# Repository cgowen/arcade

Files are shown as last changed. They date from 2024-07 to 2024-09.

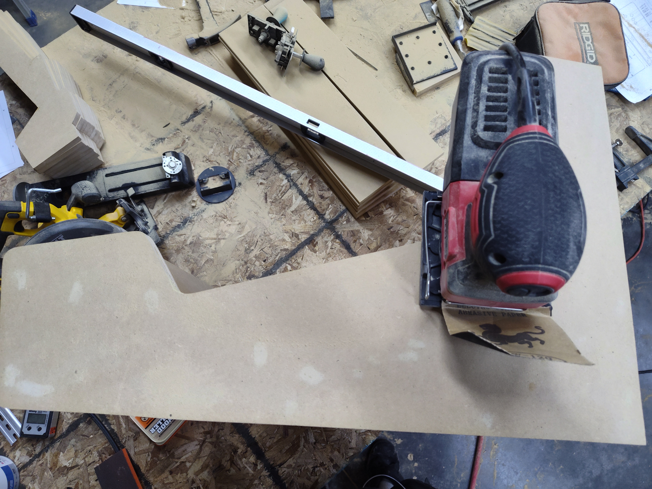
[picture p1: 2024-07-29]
Build Photos/IMG_20240721_163146368_HDR.jpg

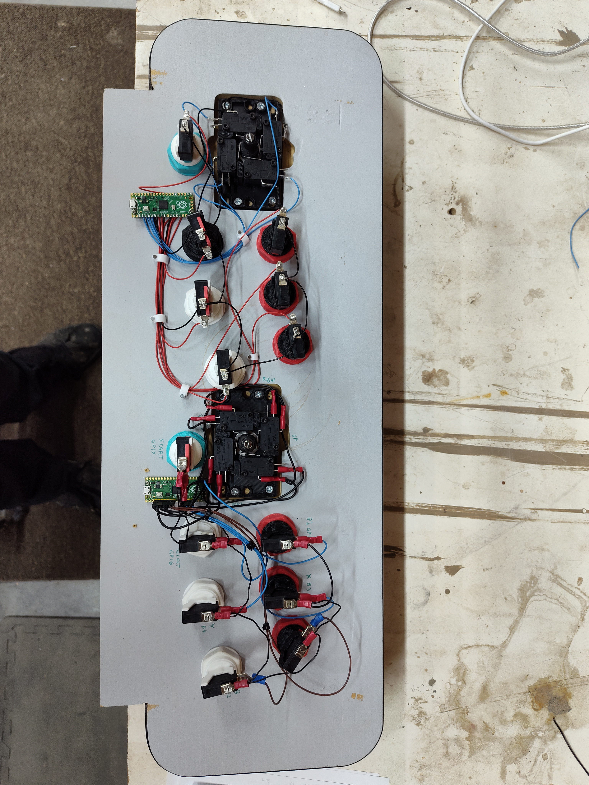
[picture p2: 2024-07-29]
Build Photos/IMG_20240728_184047468.jpg

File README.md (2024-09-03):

This project aims to be a skill building excercise for CAD design, woodworking and electronics with some 3D printing mixed in.
This page is meant to be a project log as well as a bill of materials for the project



Project links:
OnShape cabinet assembly: https://cad.onshape.com/documents/2fd70302999bd67d294d9c58/w/49d1ede729af55697e110dd8/e/55eb390648f6f1f8dbbdfb2d

3D printed button assembly: https://cad.onshape.com/documents/6f03fd3a26405f290bf9d3a9/w/7fcbac6da55869d88fd815f0/e/7aa5c642de203e99c9db4843

Joystick Assembly: https://cad.onshape.com/documents/1d7793801d2a4d8de748bbaa/w/73db9a26cb0c9d3e88edd5c2/e/f8327efe855c3a30d43a8055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

Raspberry pi pico gamepad: (https://gp2040-ce.info/)

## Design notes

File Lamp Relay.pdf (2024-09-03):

To Audio Amplifier (5V & GND)

To relay (GPIO14, 5V, GND)

To Rpi 4 power switch
(GPIO3 & GND)

VCC
IN
GND

NC
COM
NO

## Relay

# HIGH VOLTAGE POWER UNPLUG BEFORE WIRING!!

(Wire Nut if needed)

On the SD card in the raspberry pi there is a partition named boot.

### there you will find a file named: recalbox-user-config.txt

we need to add the "enable_uart=1" to the bottom of the file.

### the red "dtoverlay" command is only for the raspberry pi 4's power switches (if you are using a raspberry pi 5 then disregard this line)

A relay is an electro magnetic switch that can handle a larger load than the raspberry pi can power by itself.

In this case that is a high voltage AC load (alternating current) Connecting this to the Pi would certainly fry it.. In fact, connecting this to us could fry us also!

Be careful and unplug your machine before wiring and have an adult present to double check your connections before testing.

This setup is using the GPIO serial port pin on the raspberry pi as a signal to turn on the relay causing the light to turn on.
Once the Raspberry Pi turns off the serial port is also shutdown causing the light to turn off.

# Change to your needs

#uncomment if you get no picture on HDMI for a default "safe" mode #hdmi_safe=1

#uncomment to force a specific HDMI mode (this will force VGA) #hdmi_group=1

#hdmi_mode=1

#Sound output. Set to 0 or comment for autodetect, 1 for DVI, 2 to force HDMI. #hdmi_drive=2

config_hdmi_boost=0

#uncomment for composite PAL

#sdtv_mode=2

#uncomment for lirc-rpi

#dtoverlay=lirc-rpi

#uncomment if you have chinese TV display and display is garbled or slow #hdmi_ignore_edid=0xa5000080

overscan_scale=0
gpio=14=op,dh
dtoverlay=gpio-shutdown,gpio_pin=3,active_low=1,debounce=1500
enable_uart=1

/boot/recalbox-user-config.txt

# Software Configuration:

# Wiring:

Cut open insulation around romex wire to get to black wire inside. connect one side of the black wire you cut to the COM terminal and the other side to the NO terminal. NO is short for "normally open" which means that by default the connection is not closed until a signal is present to tell the relay to turn on.

Only the black wire needs to be cut but if you cut the others use wire nuts to put them back together
(tighten the nuts well and make sure there are no extra wires hanging out!)

GPIO Header location

# What is a relay?

The GND and 5V connections may be different on your board from what is shown here. The exact pin location doesnt matter so long as the connections are correct.
All GND pins are connected together and both 5V lines are also connected.

The important thing to pay attention to is that 5V and GND are not mixed up and that the GPIO pins are connected to the header where they need to be.

GPIO14 = relay in
GPIO3 = power switch (rpi 4 only)

# Notice!

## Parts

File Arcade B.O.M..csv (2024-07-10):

 |  |  |  |  |  | OnShape CAD Model
QTY | UNIT | DESCRIPTION | VENDOR | PRICE | TIOTAL | PURPOSE
1 | EA | Short Micro USB Cable 1ft [5 Pack] USB 2.0 Micro USB Charging Cable Android Charger Cord for Samsung Galaxy S7 Edge S6 J7 Note 5 LG Kindle Sony PS4 TV Stick Smartphones (Black) | Amazon | $1.59 | $1.59 | Connecting Raspberry Pis to Picos
1 | EA | 19" Dell P1913T 1400x1050 LCD Monitors | ebay | $23.00 | $23.00 | Arcade screen
8 | EA | 125V/250V 16A SPDT Snap Action Button Micro Limit Switch for Microwave Oven Door Arcade KW3 by MUZHI(12Pack) | Amazon | $0.63 | $5.06 | Each arcade controller button assembly
1 | 10 FT | 100FT 20AWG Electrical Wire, 20/2 Gauge Oxygen Free Copper 12V/24V DC Red Black Zip Cord Wire Car Audio Extension Wire, LED Strip Lights Hookup Wire for Led Strips Single Color 3528 5050 | Amazon | $1.60 | $1.60 | Switch and Joystick wiring.
1 | EA | Sanwa JLF OEM Shaft | Paradise Arcade Shop | $2.00 | $2.00 | Arcade Joystick Assemblies
1 | EA | PAS JLF 2 lbf Custom Spring | Paradise Arcade Shop | $1.25 | $1.25 | Arcade Joystick Assemblies
3 | EA | Koala Printable Clear Sticker Paper - ONLY for LASER Printer - 8.5x11 Inch 20 Sheets Full Sheet 100% Transparent Label Paper for DIY Personalized Decals, Labels | Amazon | $0.45 | $1.35 | Decals
1 | EA | Raspberry Pi Pico RP2040 microcontroller - in US Stock, Ready to Ship (4 Pack) | Amazon | $5.63 | $5.63 | input controller
1 | EA | Raspberry Pi 5 - 4 GB RAM | Adafruit | $60.00 | $60.00 | Host Computer
0.25 | EA | MDF 4ft x 8ft x 3/4in Sheet |  | $60.00 | $15.00
1 | EA | Plexiglass 2ft x 3ft x 1/8in sheet |  | $39.00 | $39.00
 |  |  |  | Grand Total: | $155.47 | (per cabinet)

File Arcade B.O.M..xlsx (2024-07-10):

QTY | UNIT | DESCRIPTION | VENDOR | PRICE | TIOTAL | PURPOSE
1 | EA | Short Micro USB Cable 1ft [5 Pack] USB 2.0 Micro USB Charging Cable Android Charger Cord for Samsung Galaxy S7 Edge S6 J7 Note 5 LG Kindle Sony PS4 TV Stick Smartphones (Black) | Amazon (https://www.amazon.com/Android-Compatible-Smartphones-Charging-Stations/dp/B095JZSHXQ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) | $1.59 | $1.59 | Connecting Raspberry Pis to Picos
1 | EA | 19" Dell P1913T 1400x1050 LCD Monitors | ebay | $23.00 | $23.00 | Arcade screen
8 | EA | 125V/250V 16A SPDT Snap Action Button Micro Limit Switch for Microwave Oven Door Arcade KW3 by MUZHI(12Pack) | Amazon (https://www.amazon.com/dp/B083C113YL?ref=ppx_yo2ov_dt_b_product_details&th=1) | $0.63 | $5.06 | Each arcade controller button assembly
1 | 10 FT | 100FT 20AWG Electrical Wire, 20/2 Gauge Oxygen Free Copper 12V/24V DC Red Black Zip Cord Wire Car Audio Extension Wire, LED Strip Lights Hookup Wire for Led Strips Single Color 3528 5050 | Amazon (https://www.amazon.com/dp/B088RCCHTG?psc=1&ref=ppx_yo2ov_dt_b_product_details) | $1.60 | $1.60 | Switch and Joystick wiring.
1 | EA | Sanwa JLF OEM Shaft | Paradise Arcade Shop (https://paradisearcadeshop.com/collections/joystick-actuators-shafts/products/sanwa-jlf-oem-shaft) | $2.00 | $2.00 | Arcade Joystick Assemblies
1 | EA | PAS JLF 2 lbf Custom Spring | Paradise Arcade Shop (https://paradisearcadeshop.com/products/pas-jlf-2-lbf-custom-spring) | $1.25 | $1.25 | Arcade Joystick Assemblies
3 | EA | Koala Printable Clear Sticker Paper - ONLY for LASER Printer - 8.5x11 Inch 20 Sheets Full Sheet 100% Transparent Label Paper for DIY Personalized Decals, Labels | Amazon (https://www.amazon.com/gp/product/B087CNQ75R/ref=ppx_yo_dt_b_asin_title_o01_s00?ie=UTF8&psc=1) | $0.45 | $1.35 | Decals
1 | EA | Raspberry Pi Pico RP2040 microcontroller - in US Stock, Ready to Ship (4 Pack) | Amazon (https://www.amazon.com/Raspberry-Pi-Pico-RP2040-microcontroller/dp/B09437S9X4) | $5.63 | $5.63 | input controller
1 | EA | Raspberry Pi 5 - 4 GB RAM | Adafruit (https://www.adafruit.com/product/5812?gad_source=1) | $60.00 | $60.00 | Host Computer
 |  | MDF
 |  | Plexiglass
 |  | Lights for marquee?
 |  |  |  | Grand Total: | $101.47

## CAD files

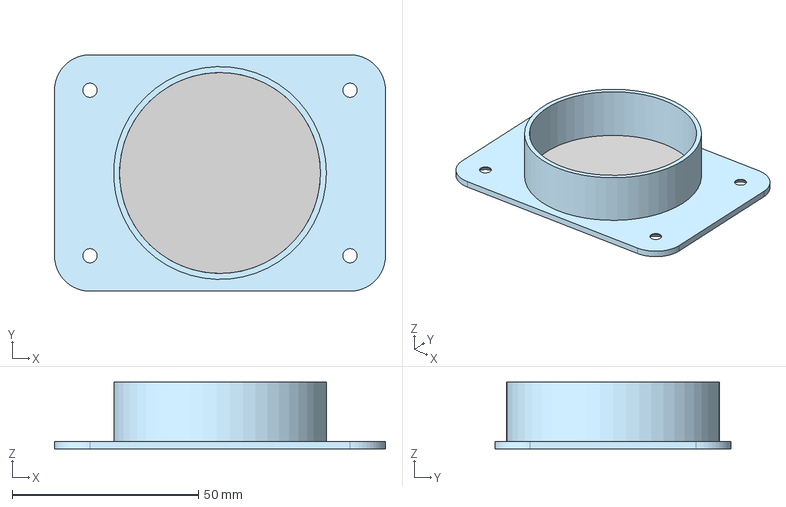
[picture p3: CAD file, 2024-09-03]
3D Printed Parts/Speaker Grill.step
88.9 x 63.5 x 17.9 mm

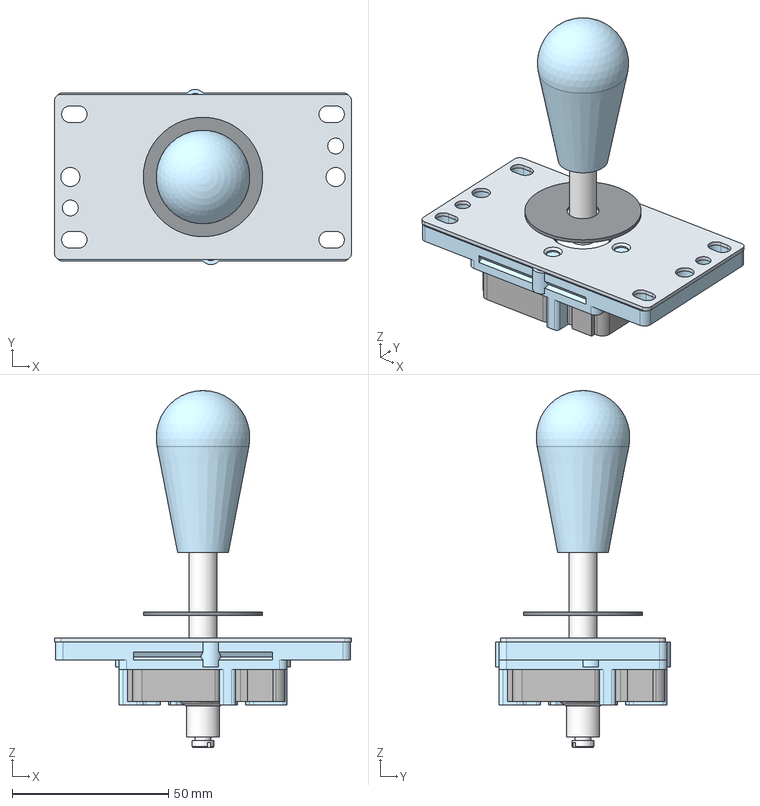
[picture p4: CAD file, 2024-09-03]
3D Printed Parts/Joystick Assm.step
95.0 x 56.0 x 114.2 mm
plate
switch body x 4
Joystick Body
pivot
Plastic Cover
knob
spring catch (top)
spring catch (btm)

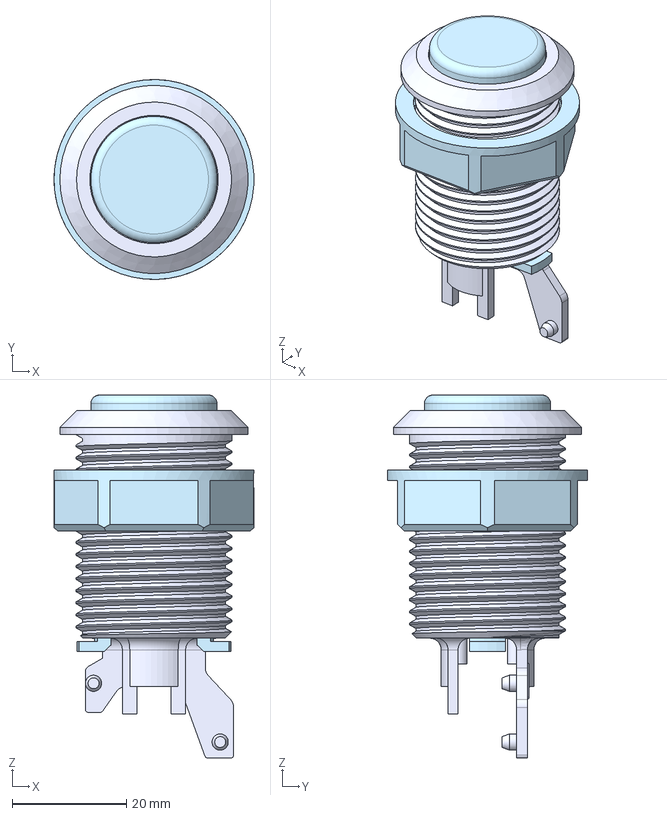
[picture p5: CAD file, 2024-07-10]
3D Printed Parts/Button Export.step
35.1 x 35.1 x 63.6 mm
Nut
Spring
Button

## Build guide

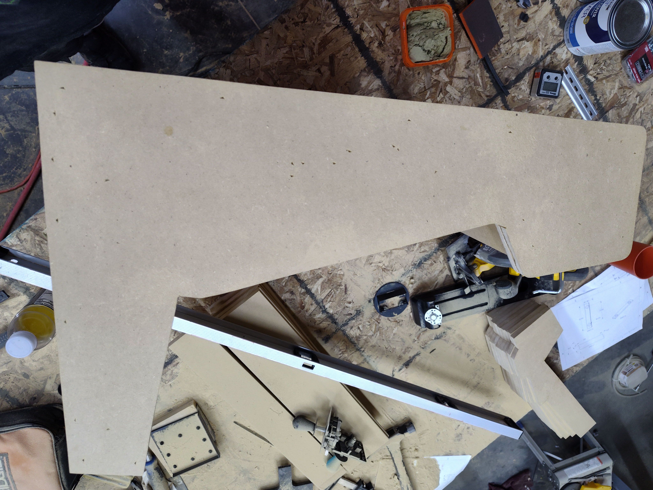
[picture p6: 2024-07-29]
Build Photos/IMG_20240721_162840555_HDR.jpg

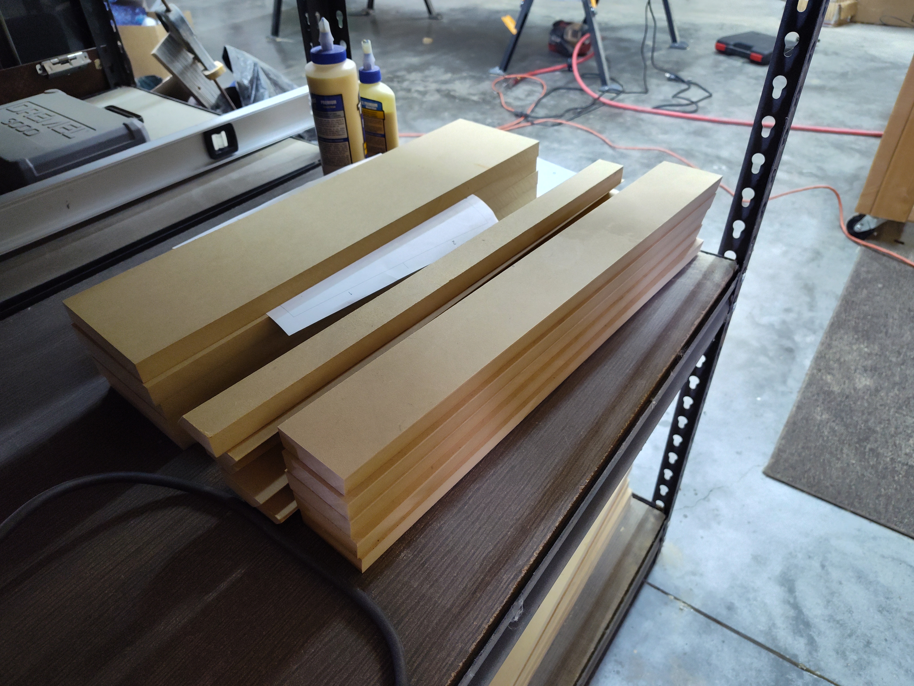
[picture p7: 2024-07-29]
Build Photos/IMG_20240721_172738716_HDR.jpg

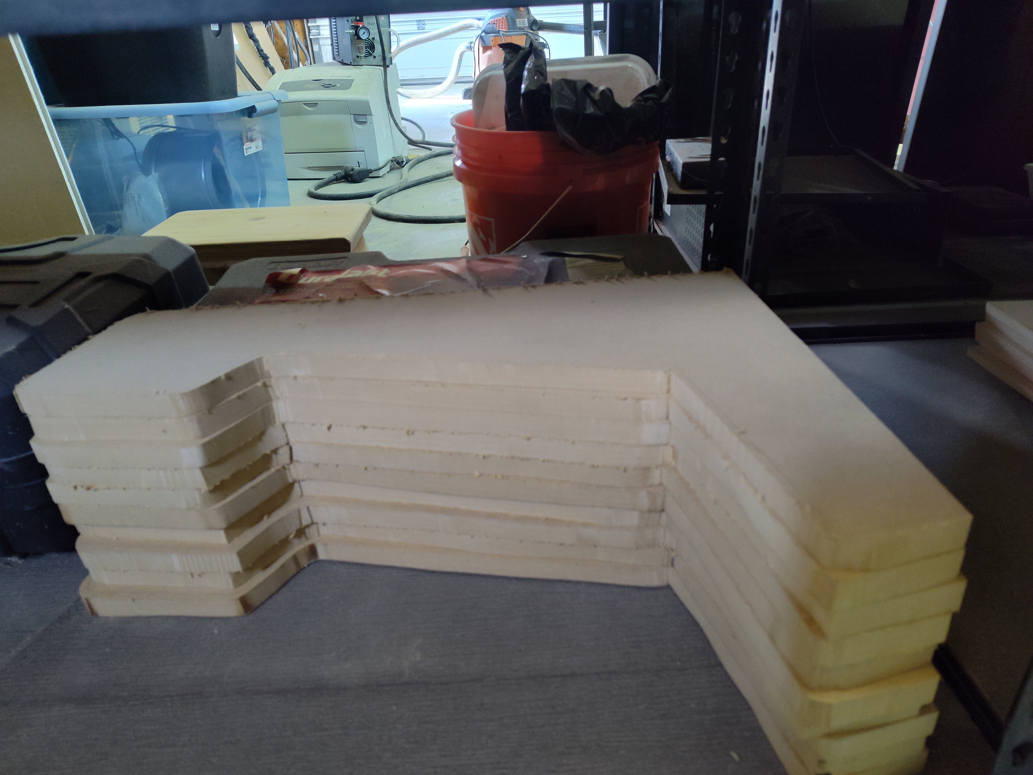
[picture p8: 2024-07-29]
Build Photos/IMG_20240721_172726751_HDR.jpg

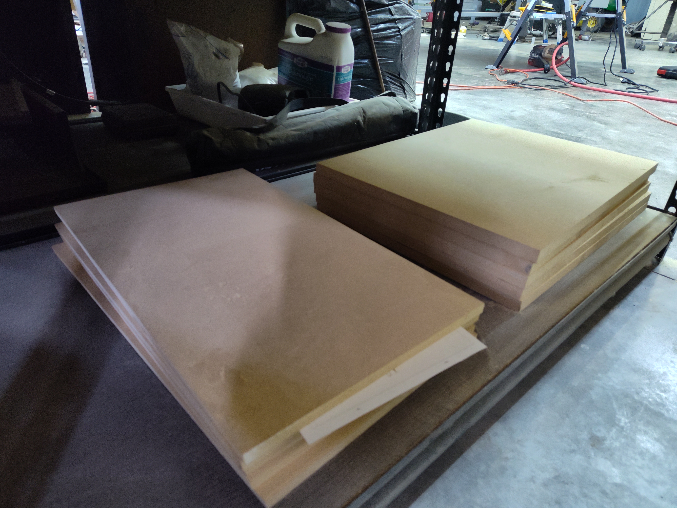
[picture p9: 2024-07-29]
Build Photos/IMG_20240721_172732919_HDR.jpg

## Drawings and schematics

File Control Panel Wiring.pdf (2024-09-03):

# Control Panel (Bottom)

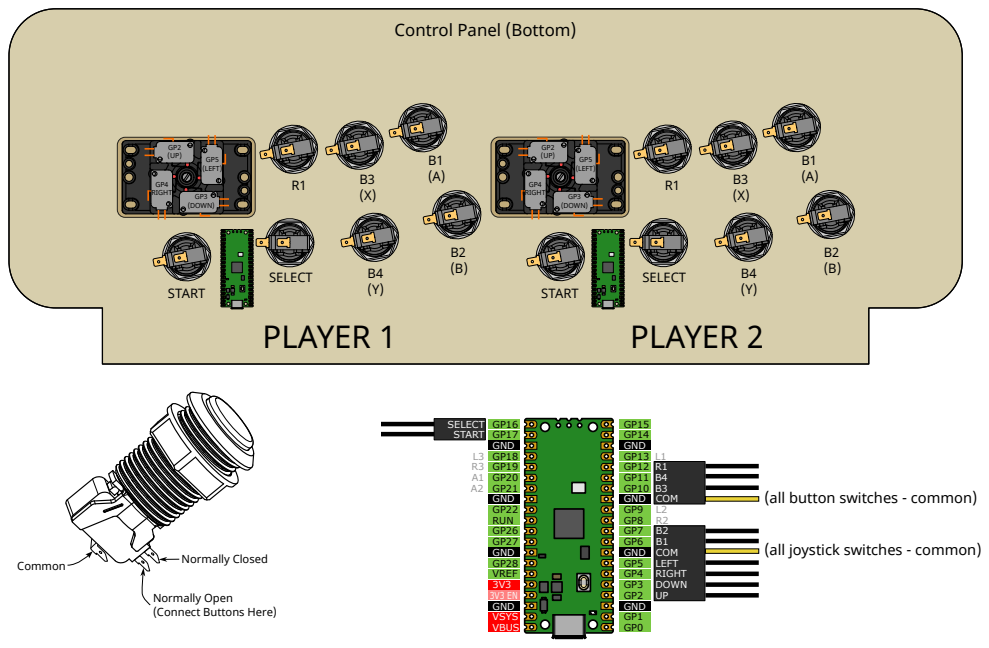
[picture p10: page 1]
GND; VBUS; VSYS; VREF; RUN; DOWN; RIGHT; LEFT; START; SELECT; COM; (all button switches - common); (LEFT); (RIGHT); (DOWN); PLAYER 1; PLAYER 2; Common; Normally Closed

(all joystick switches - common)

Normally Open
(Connect Buttons Here)

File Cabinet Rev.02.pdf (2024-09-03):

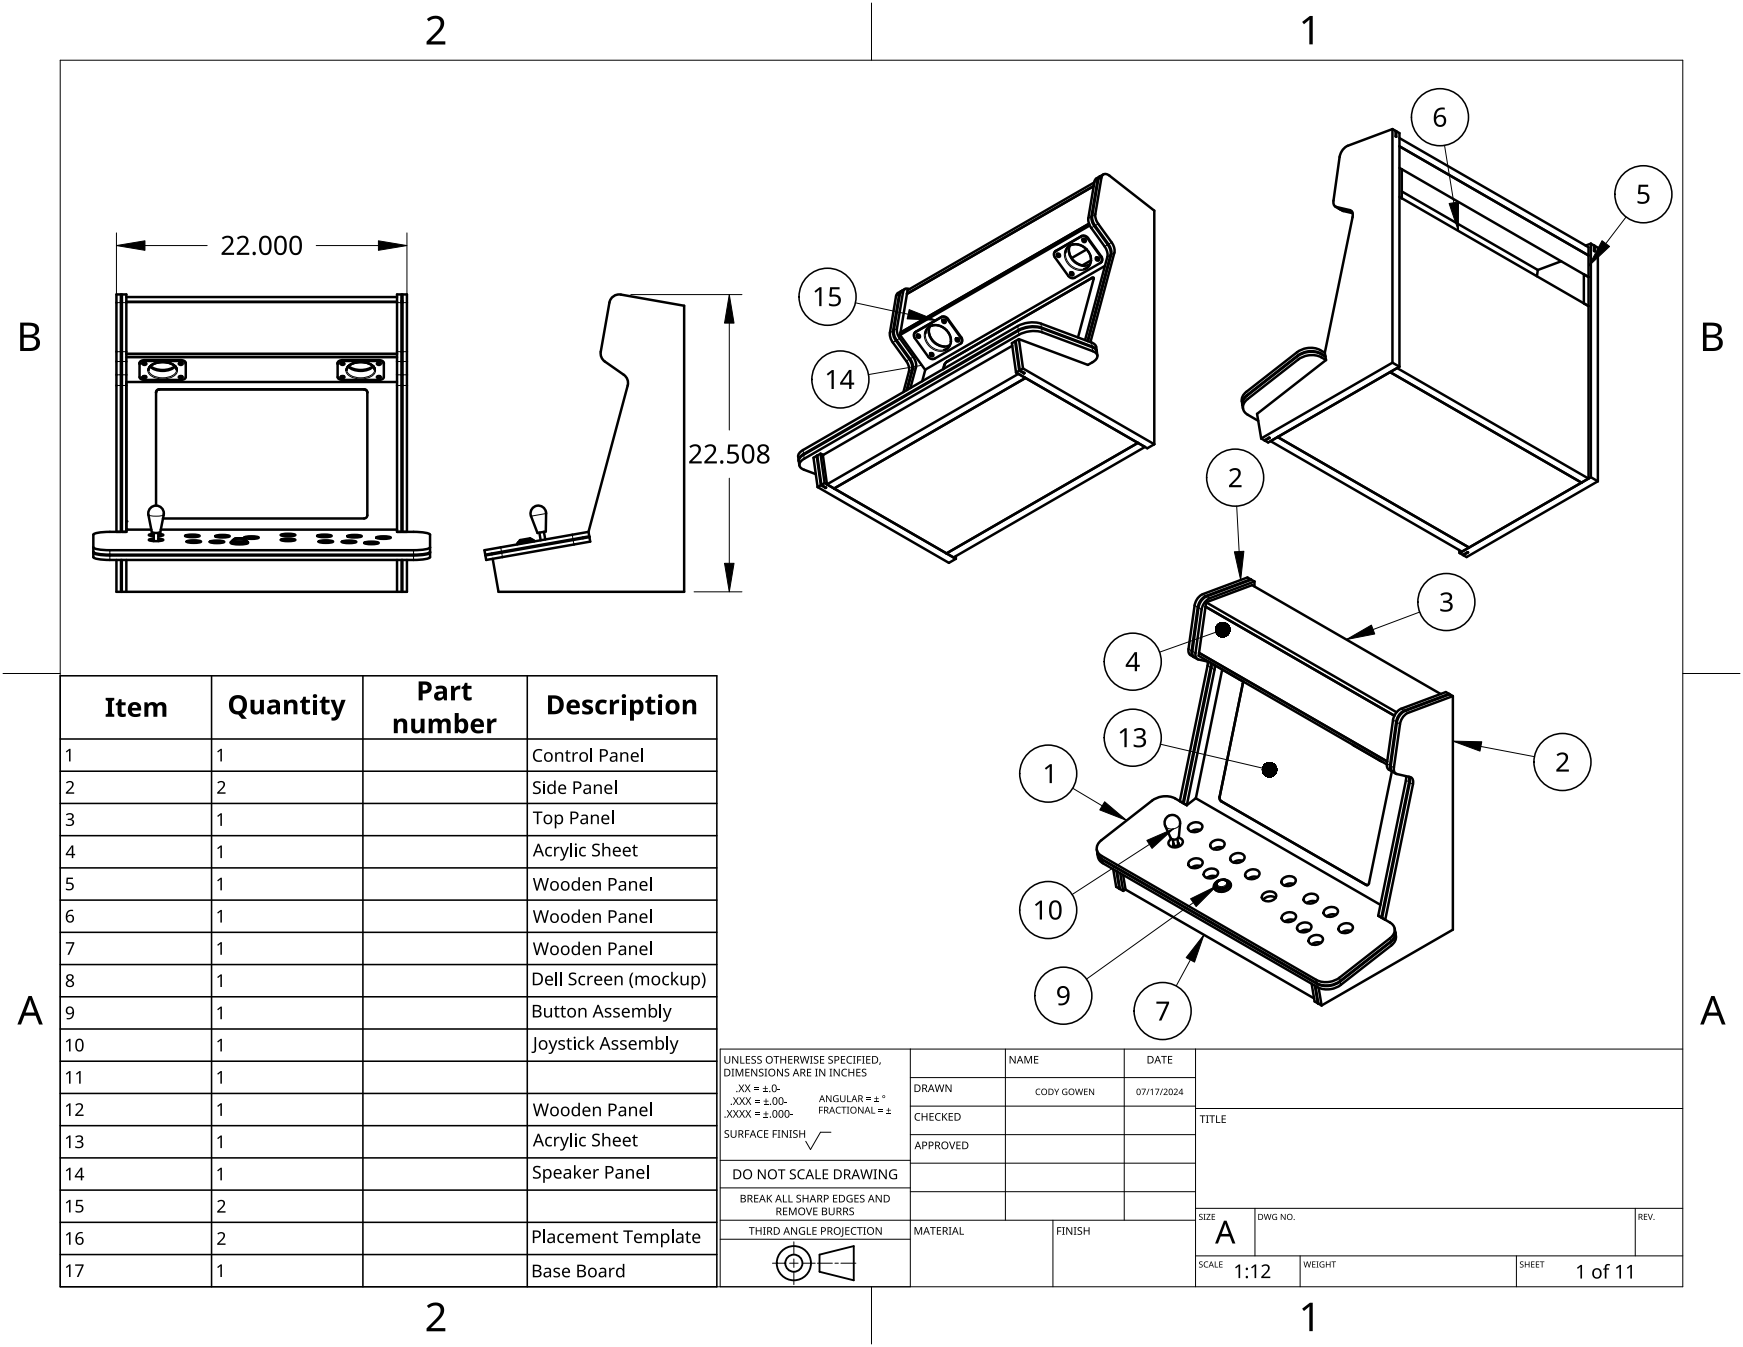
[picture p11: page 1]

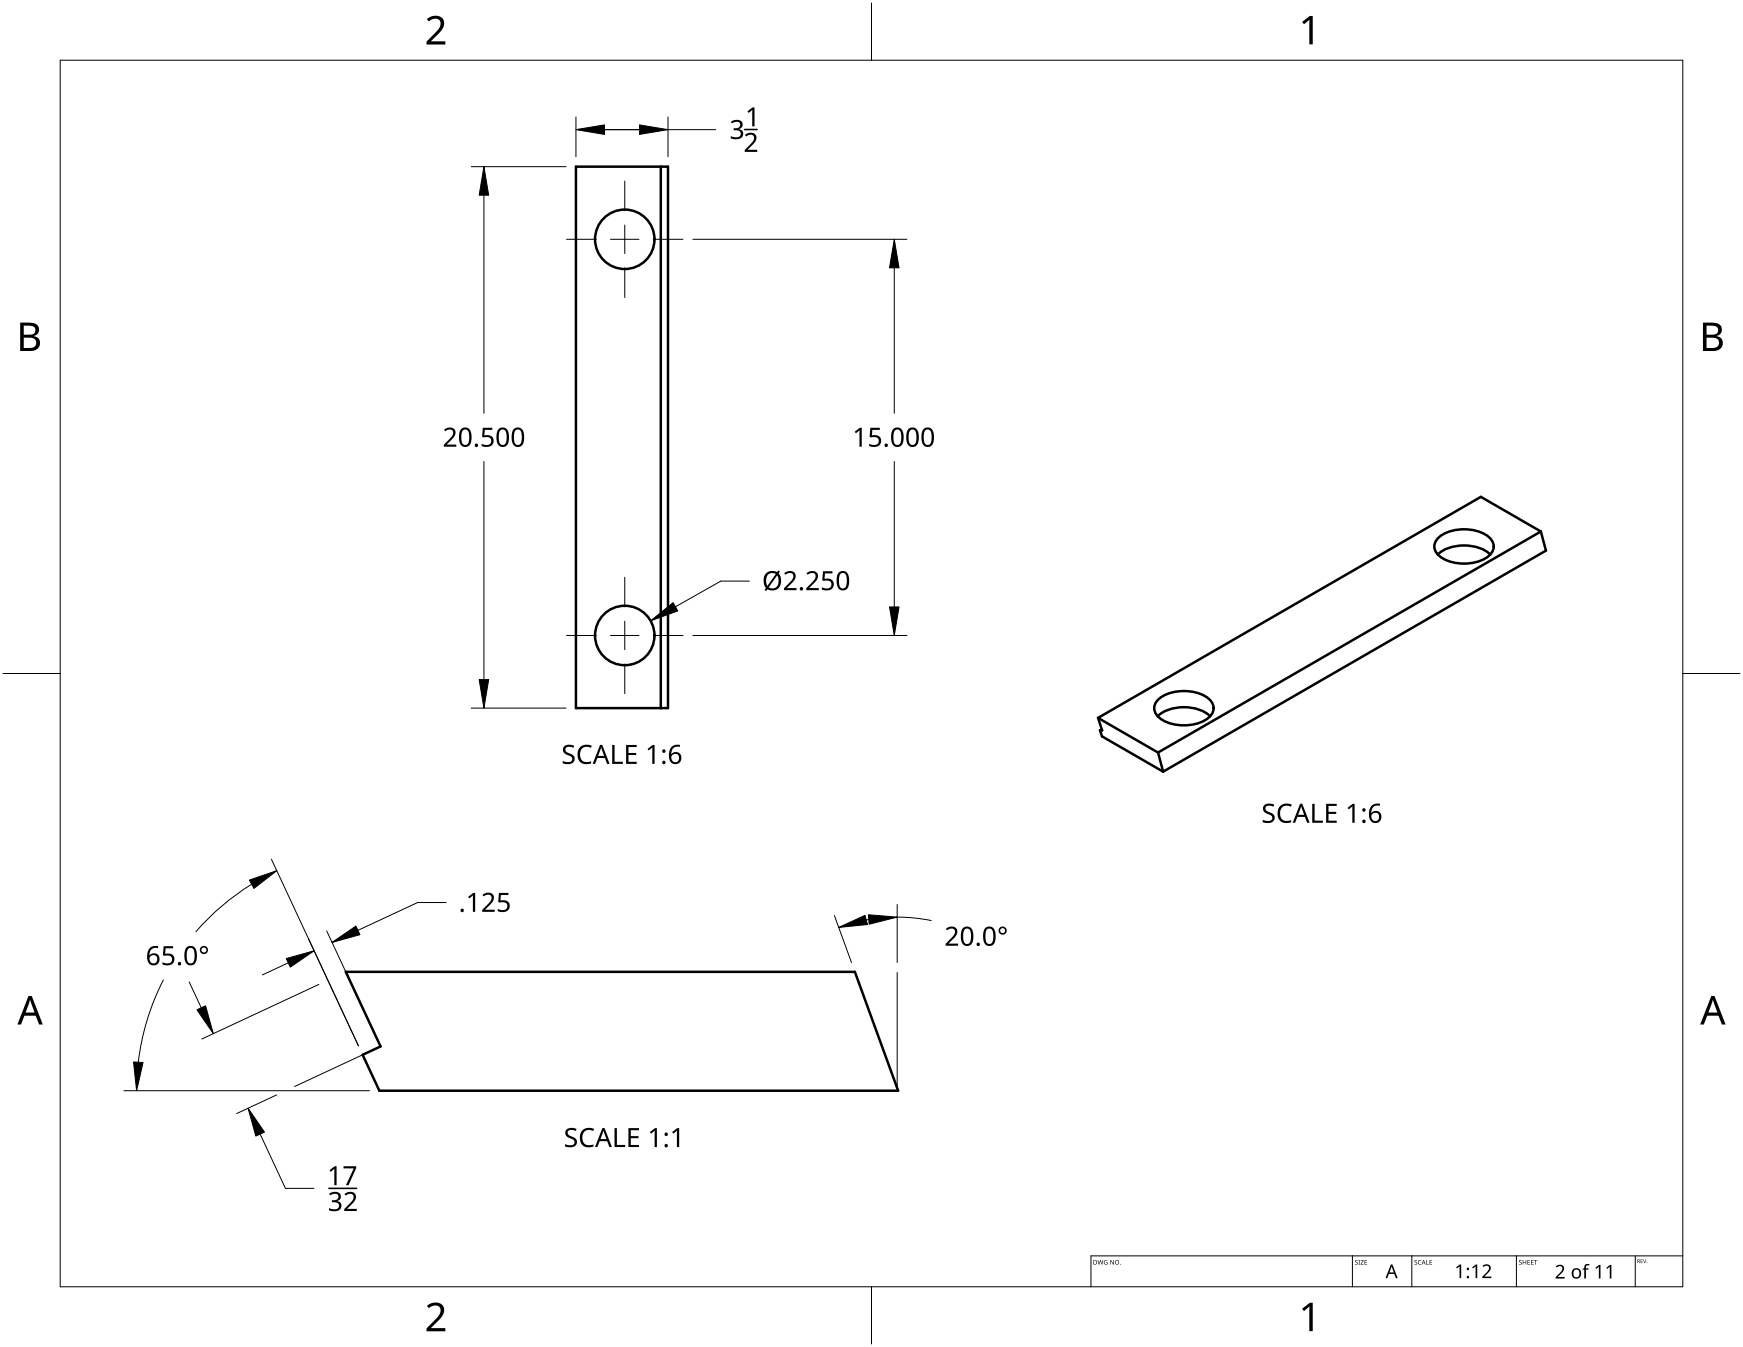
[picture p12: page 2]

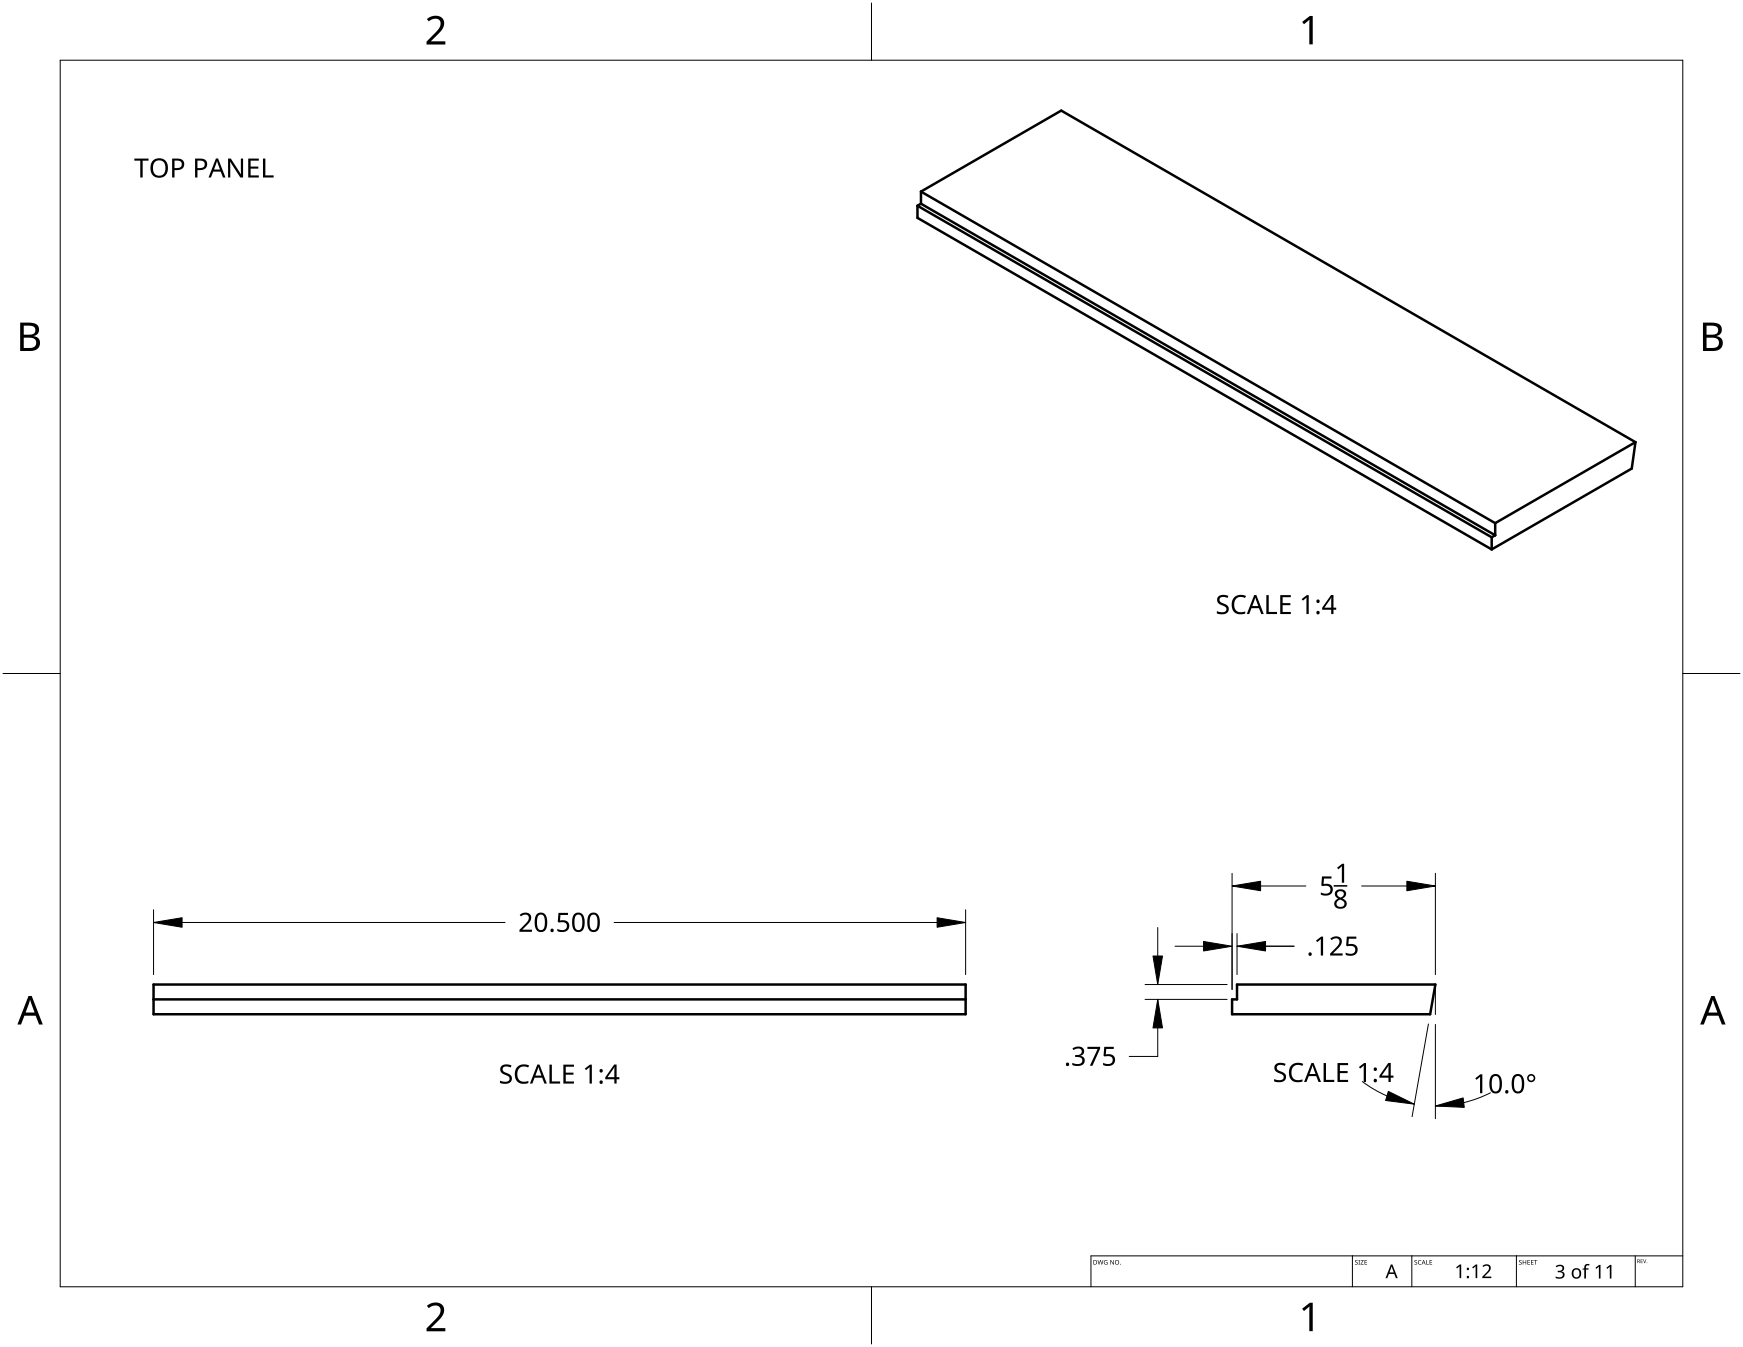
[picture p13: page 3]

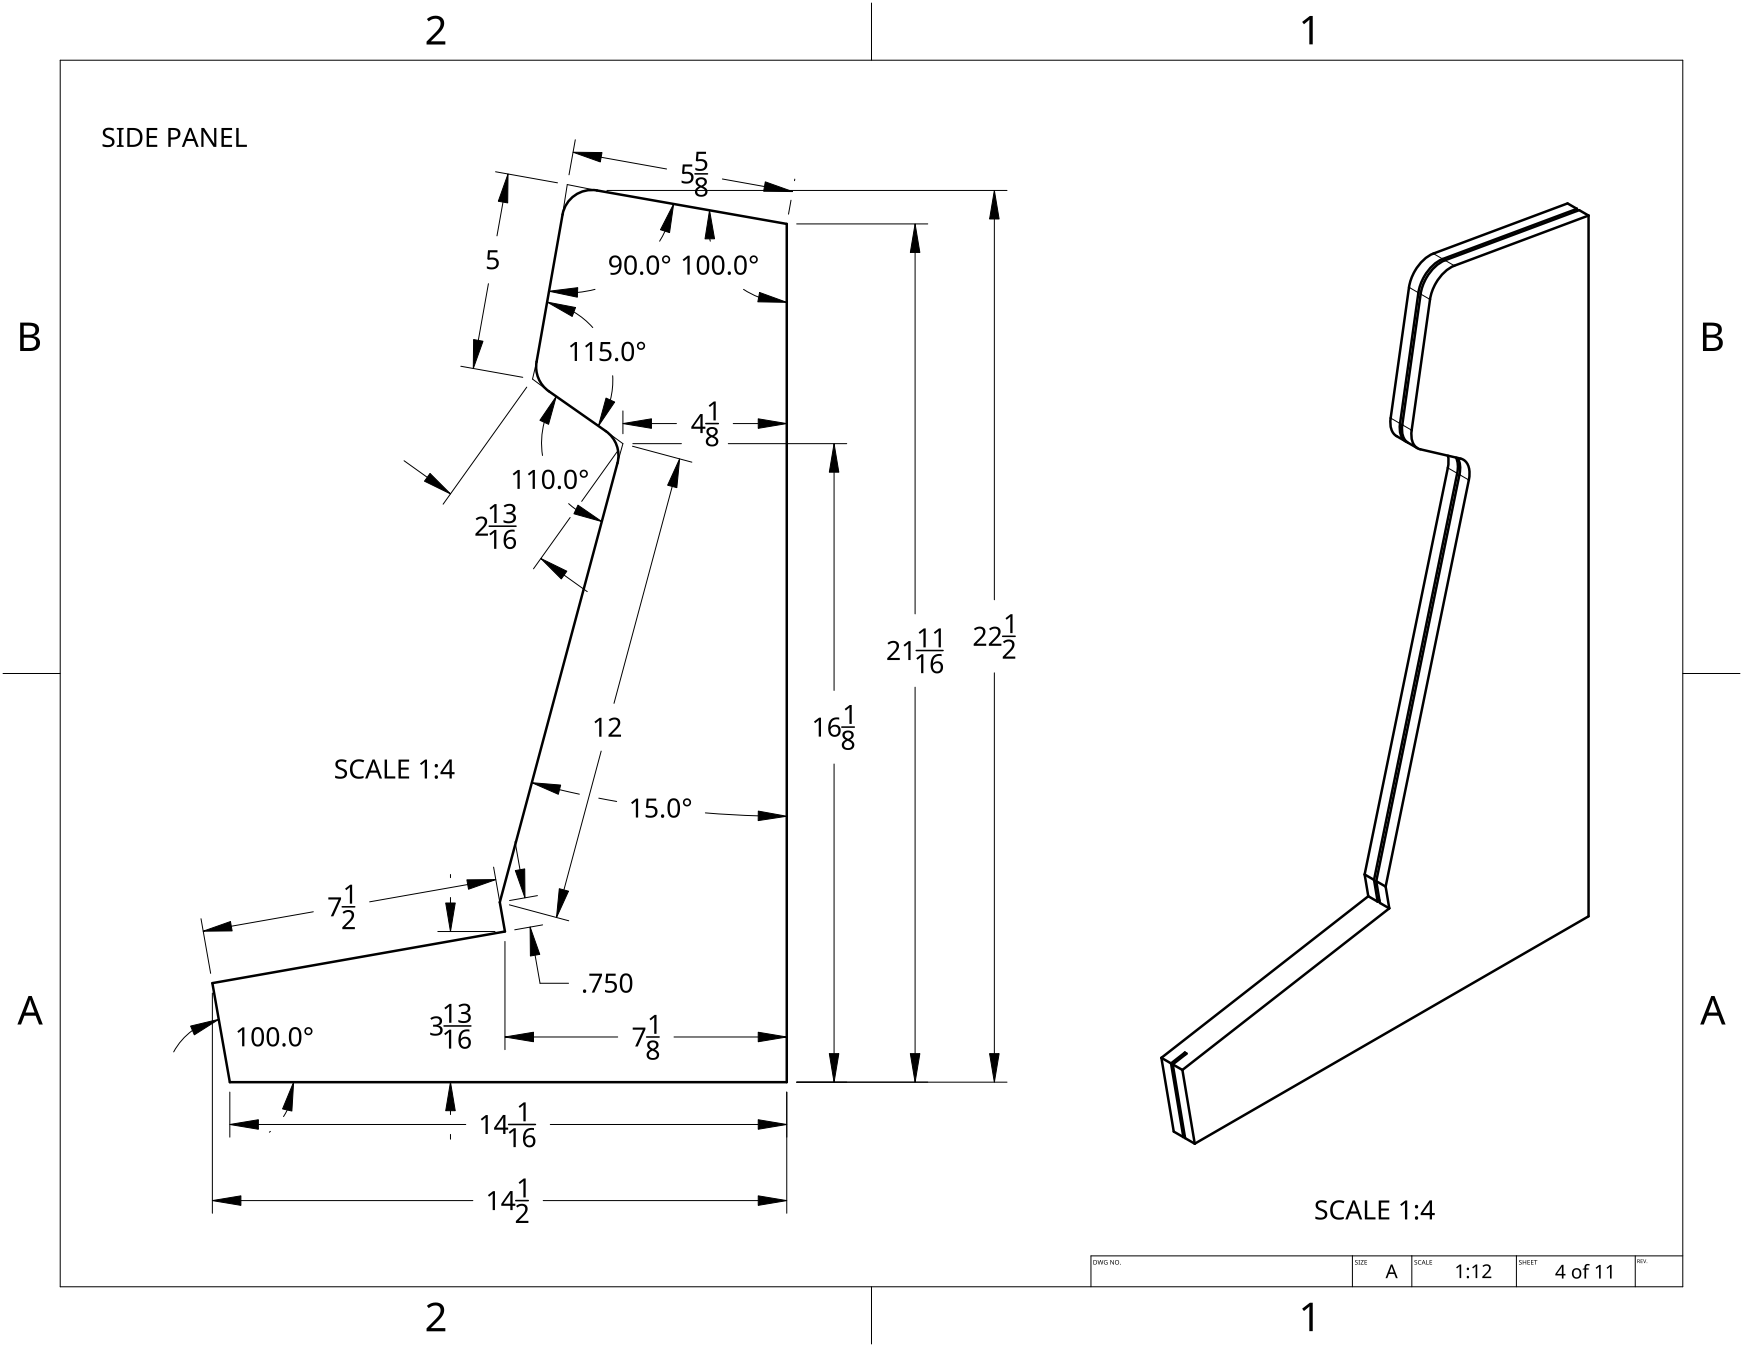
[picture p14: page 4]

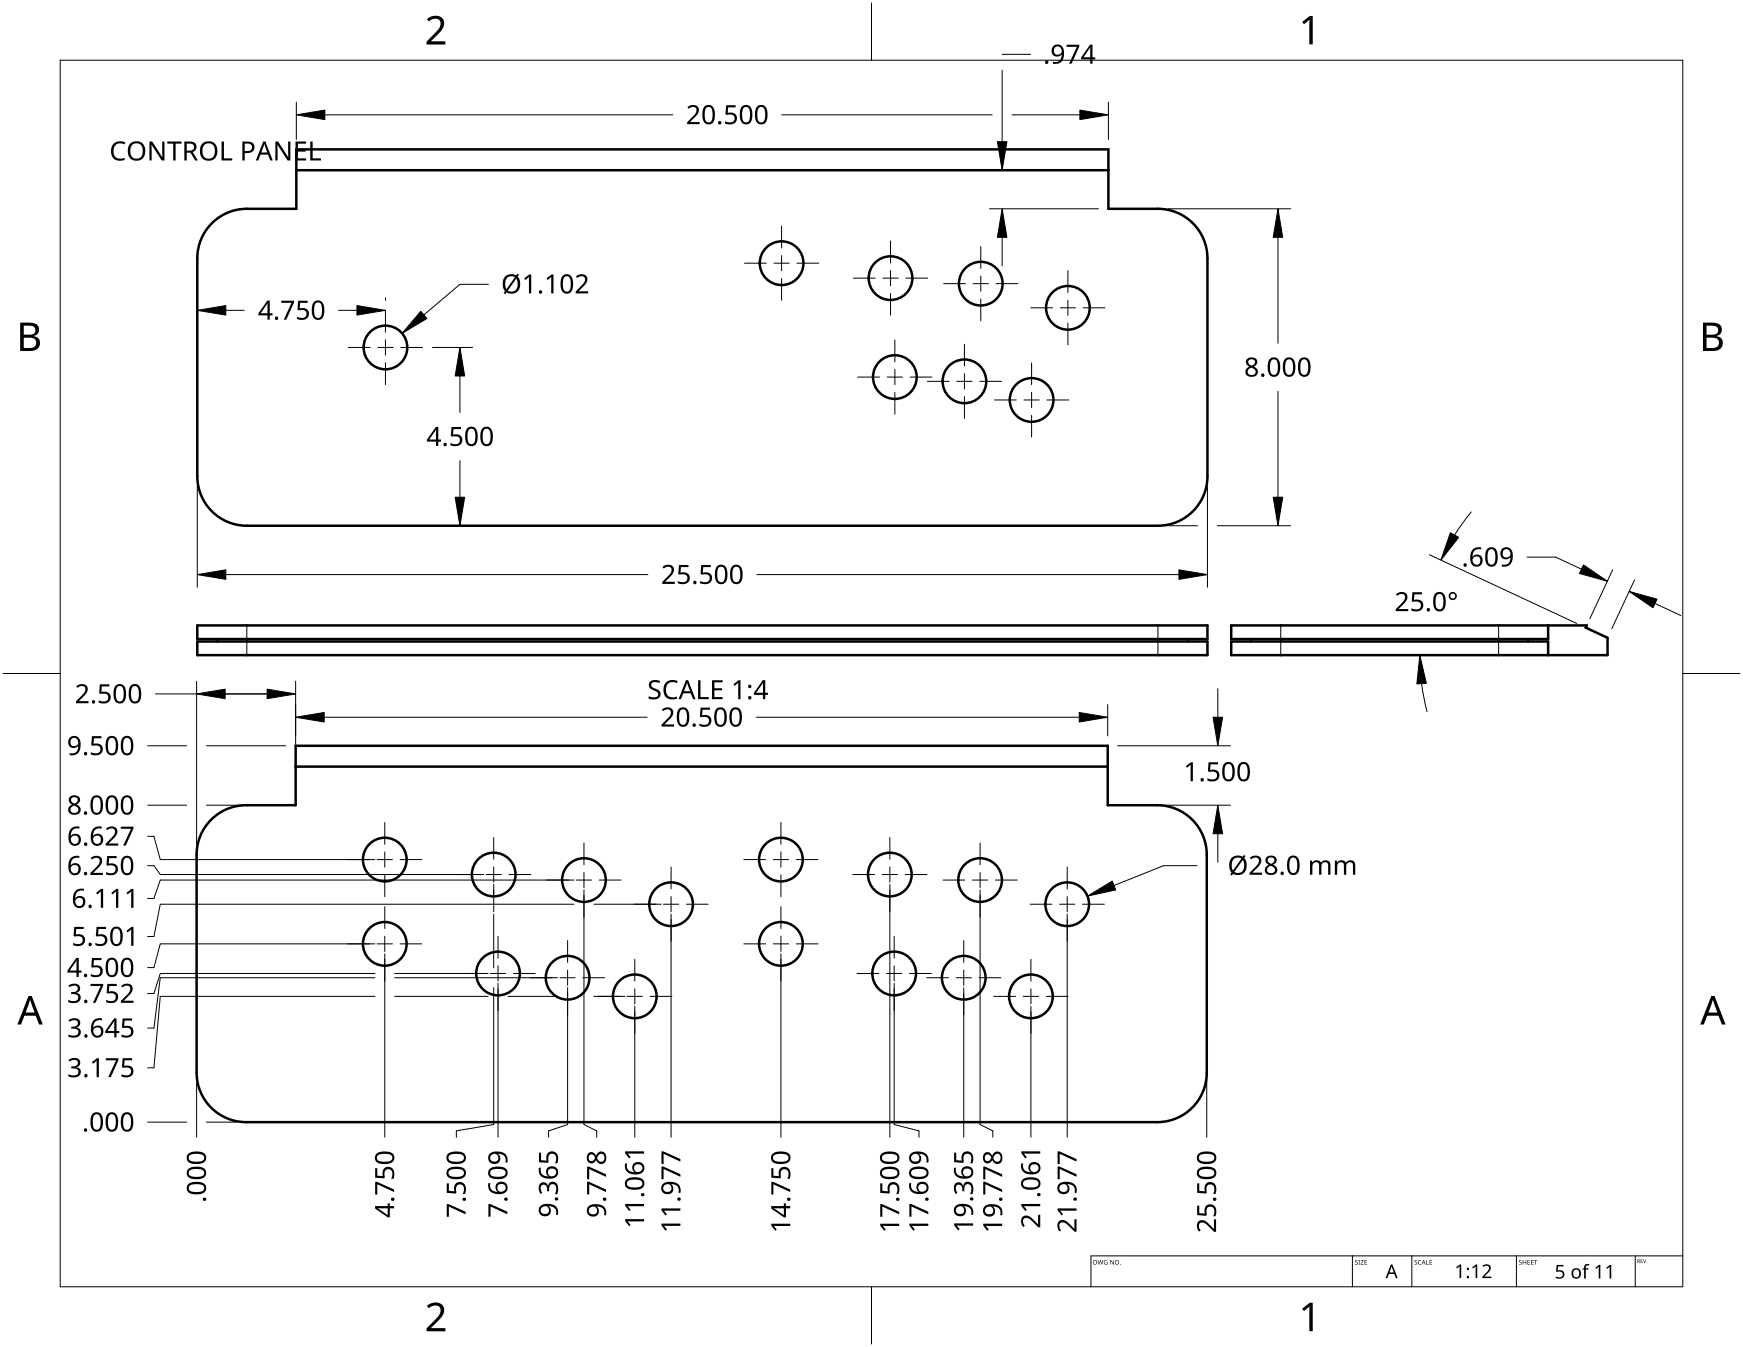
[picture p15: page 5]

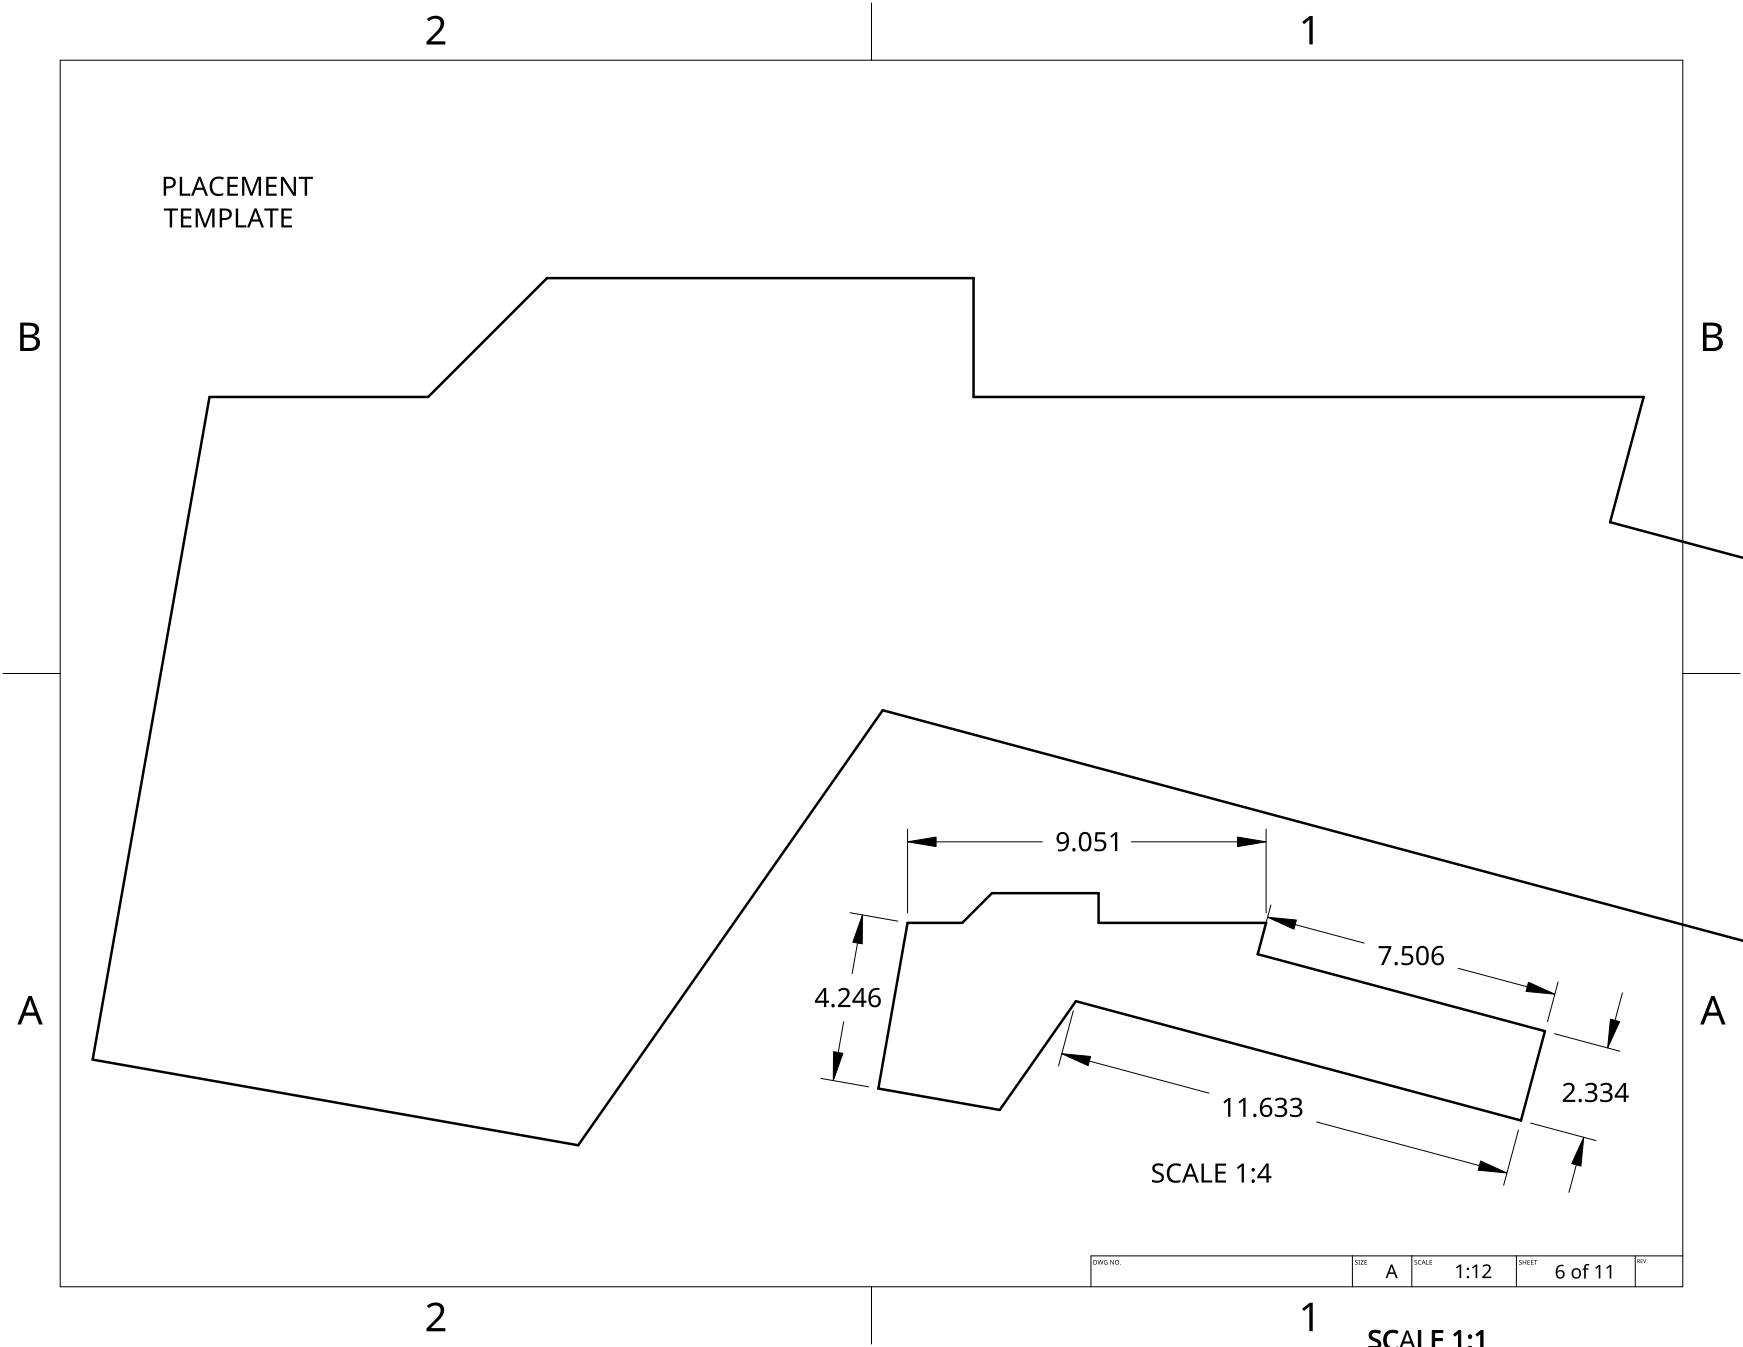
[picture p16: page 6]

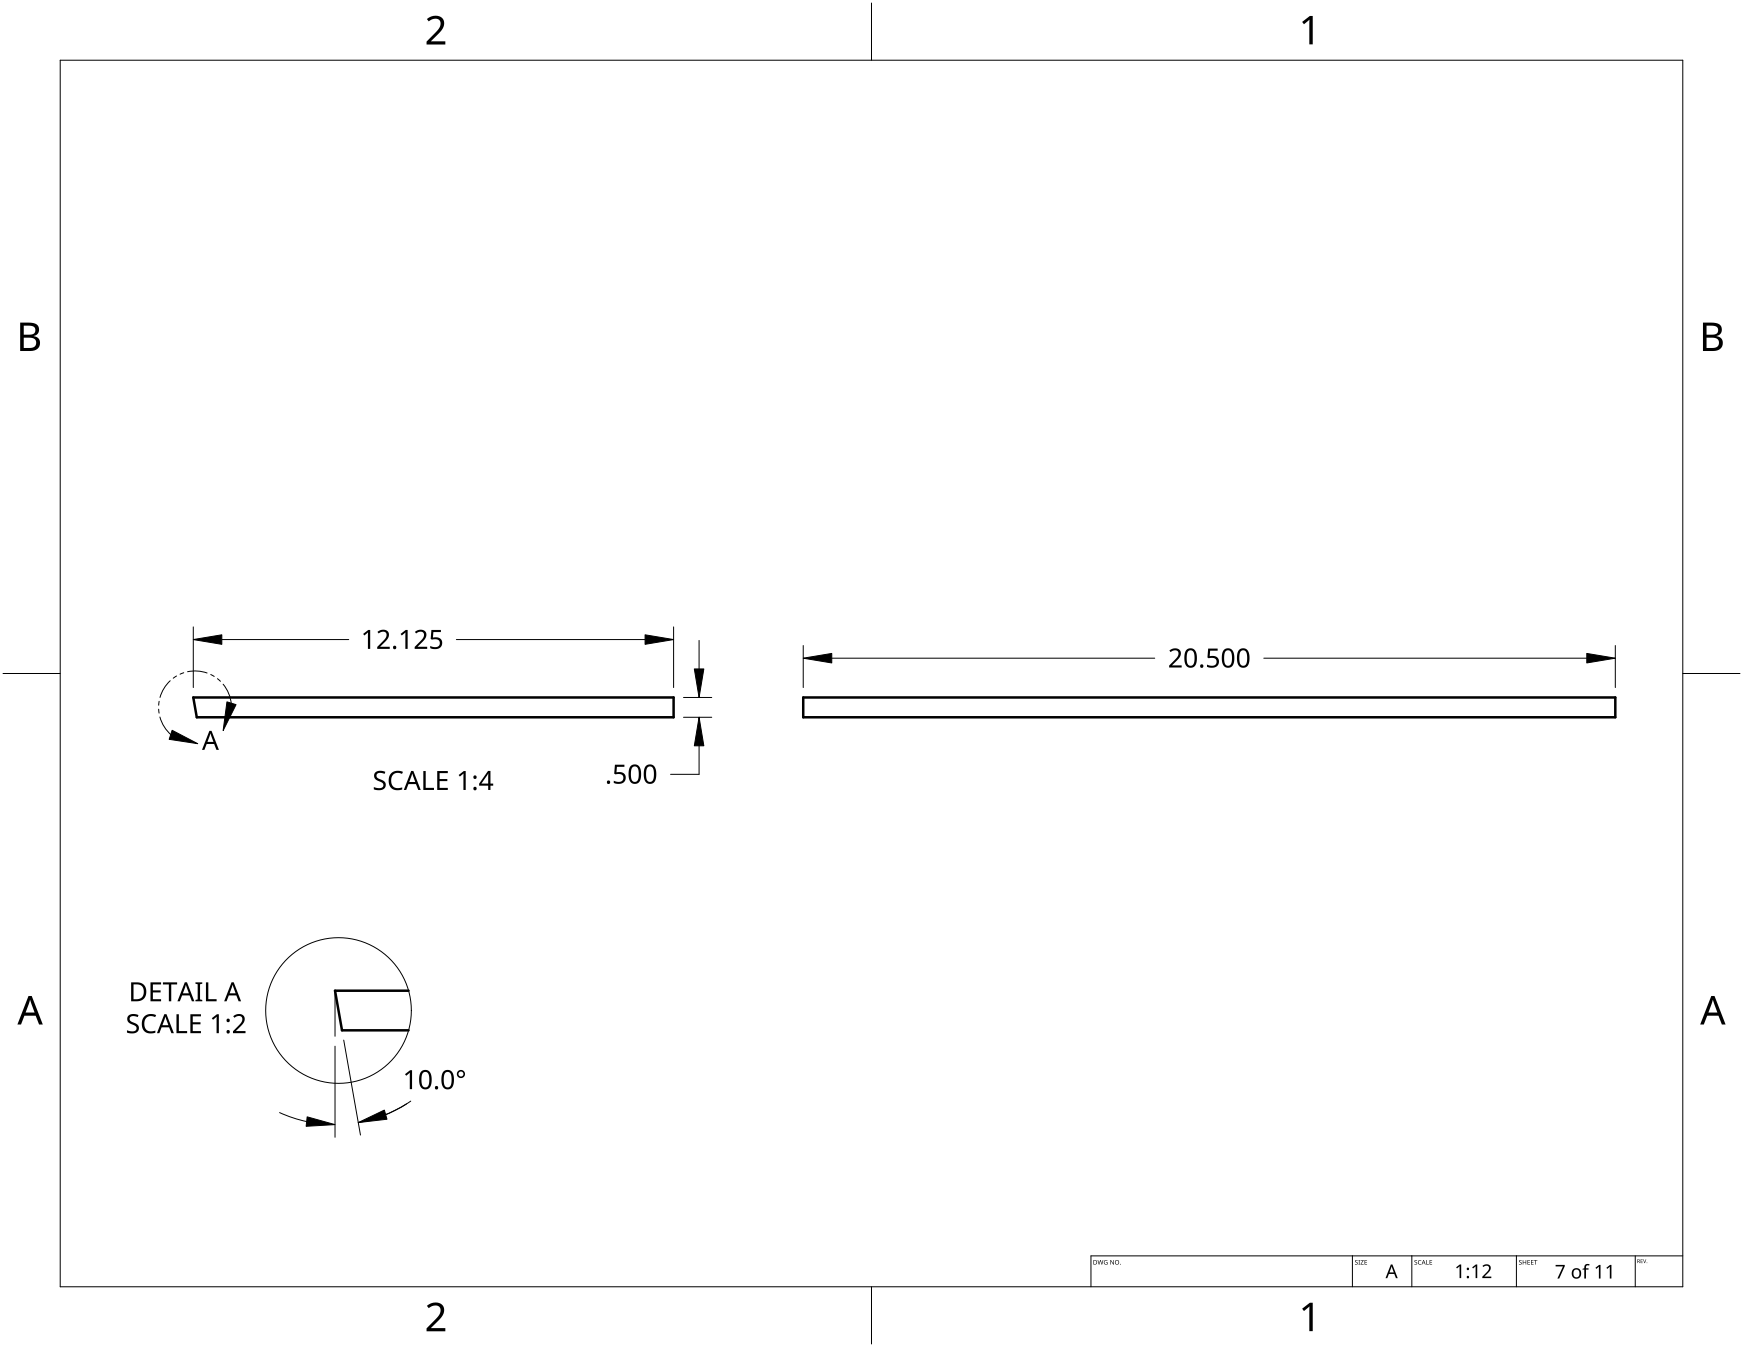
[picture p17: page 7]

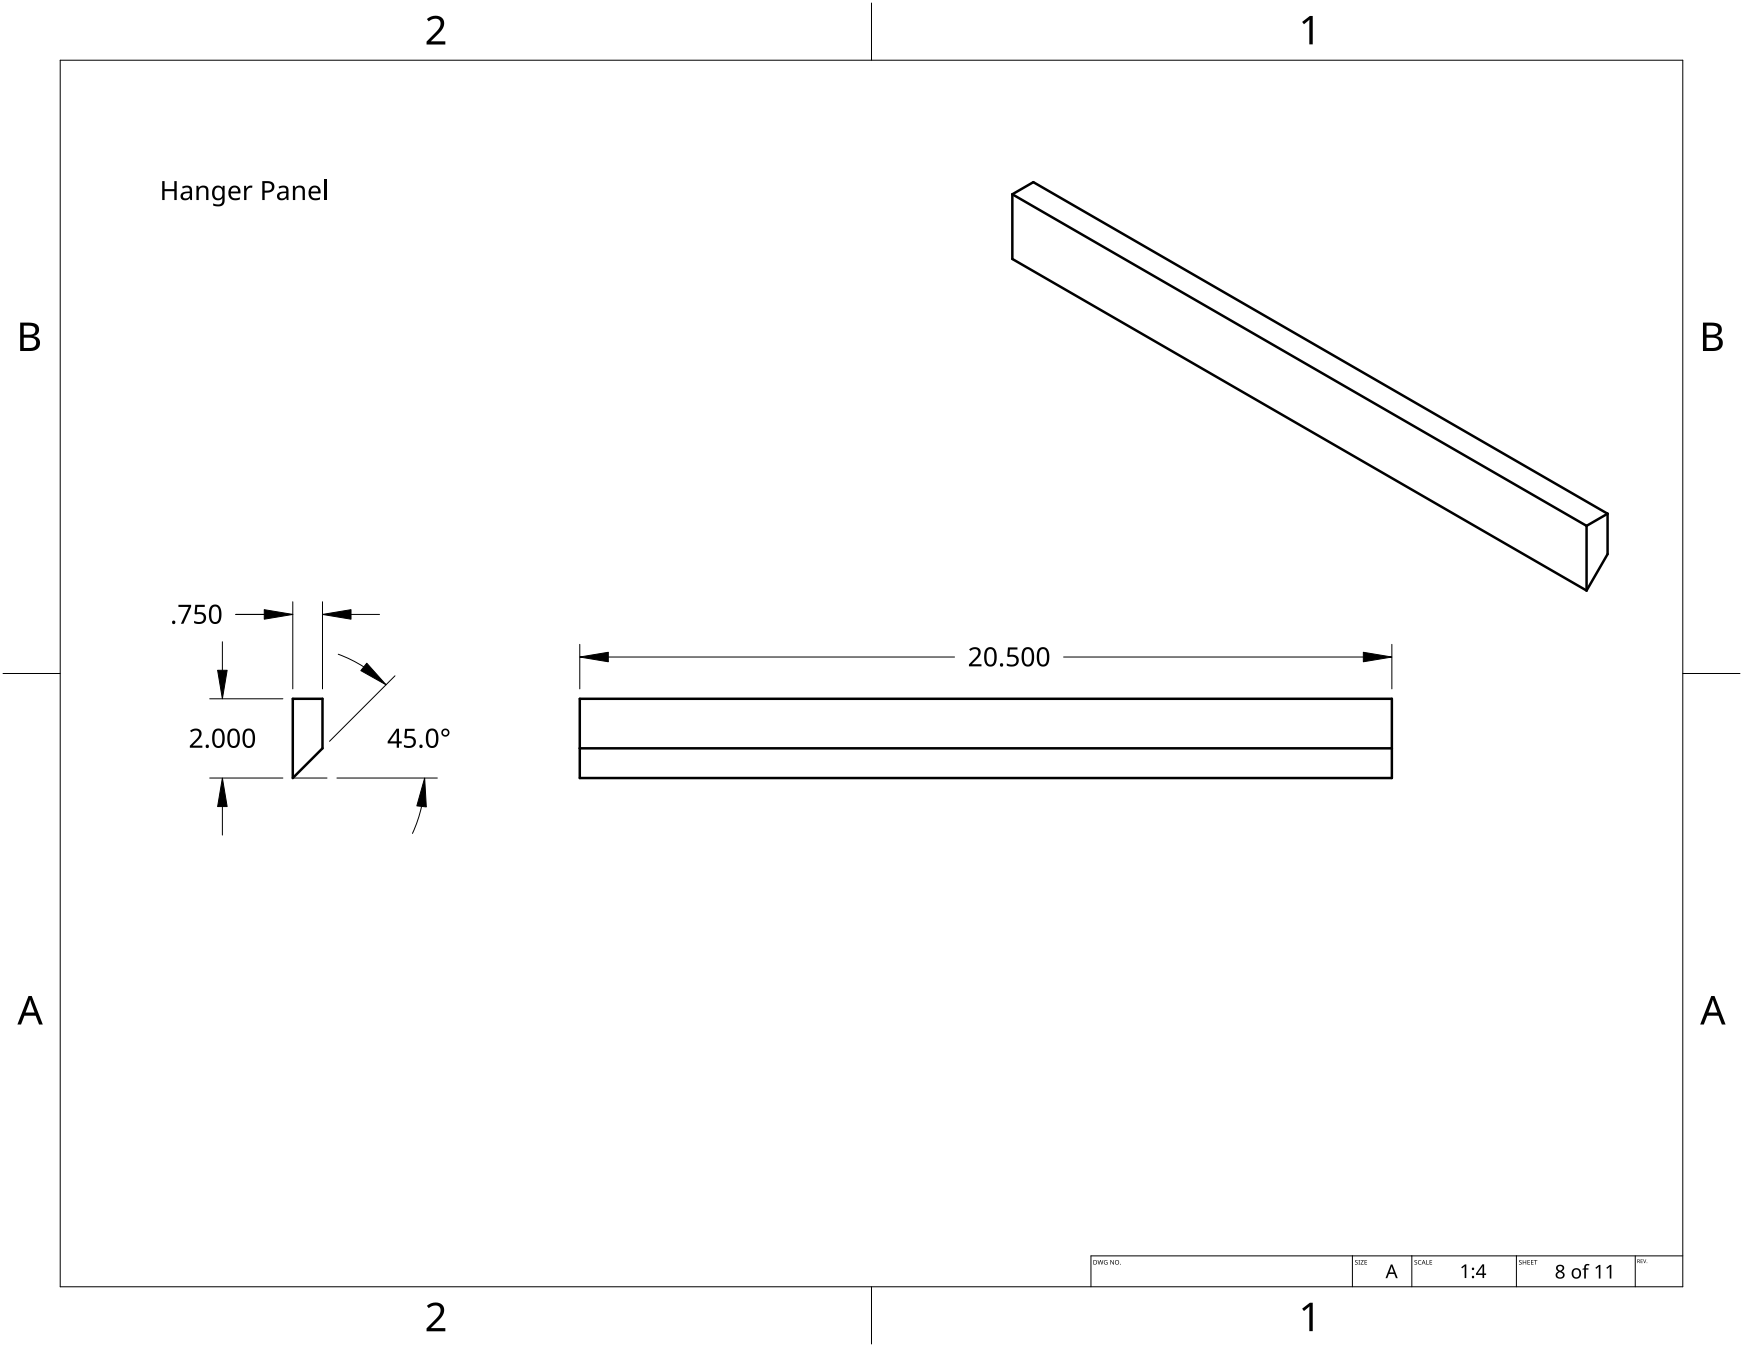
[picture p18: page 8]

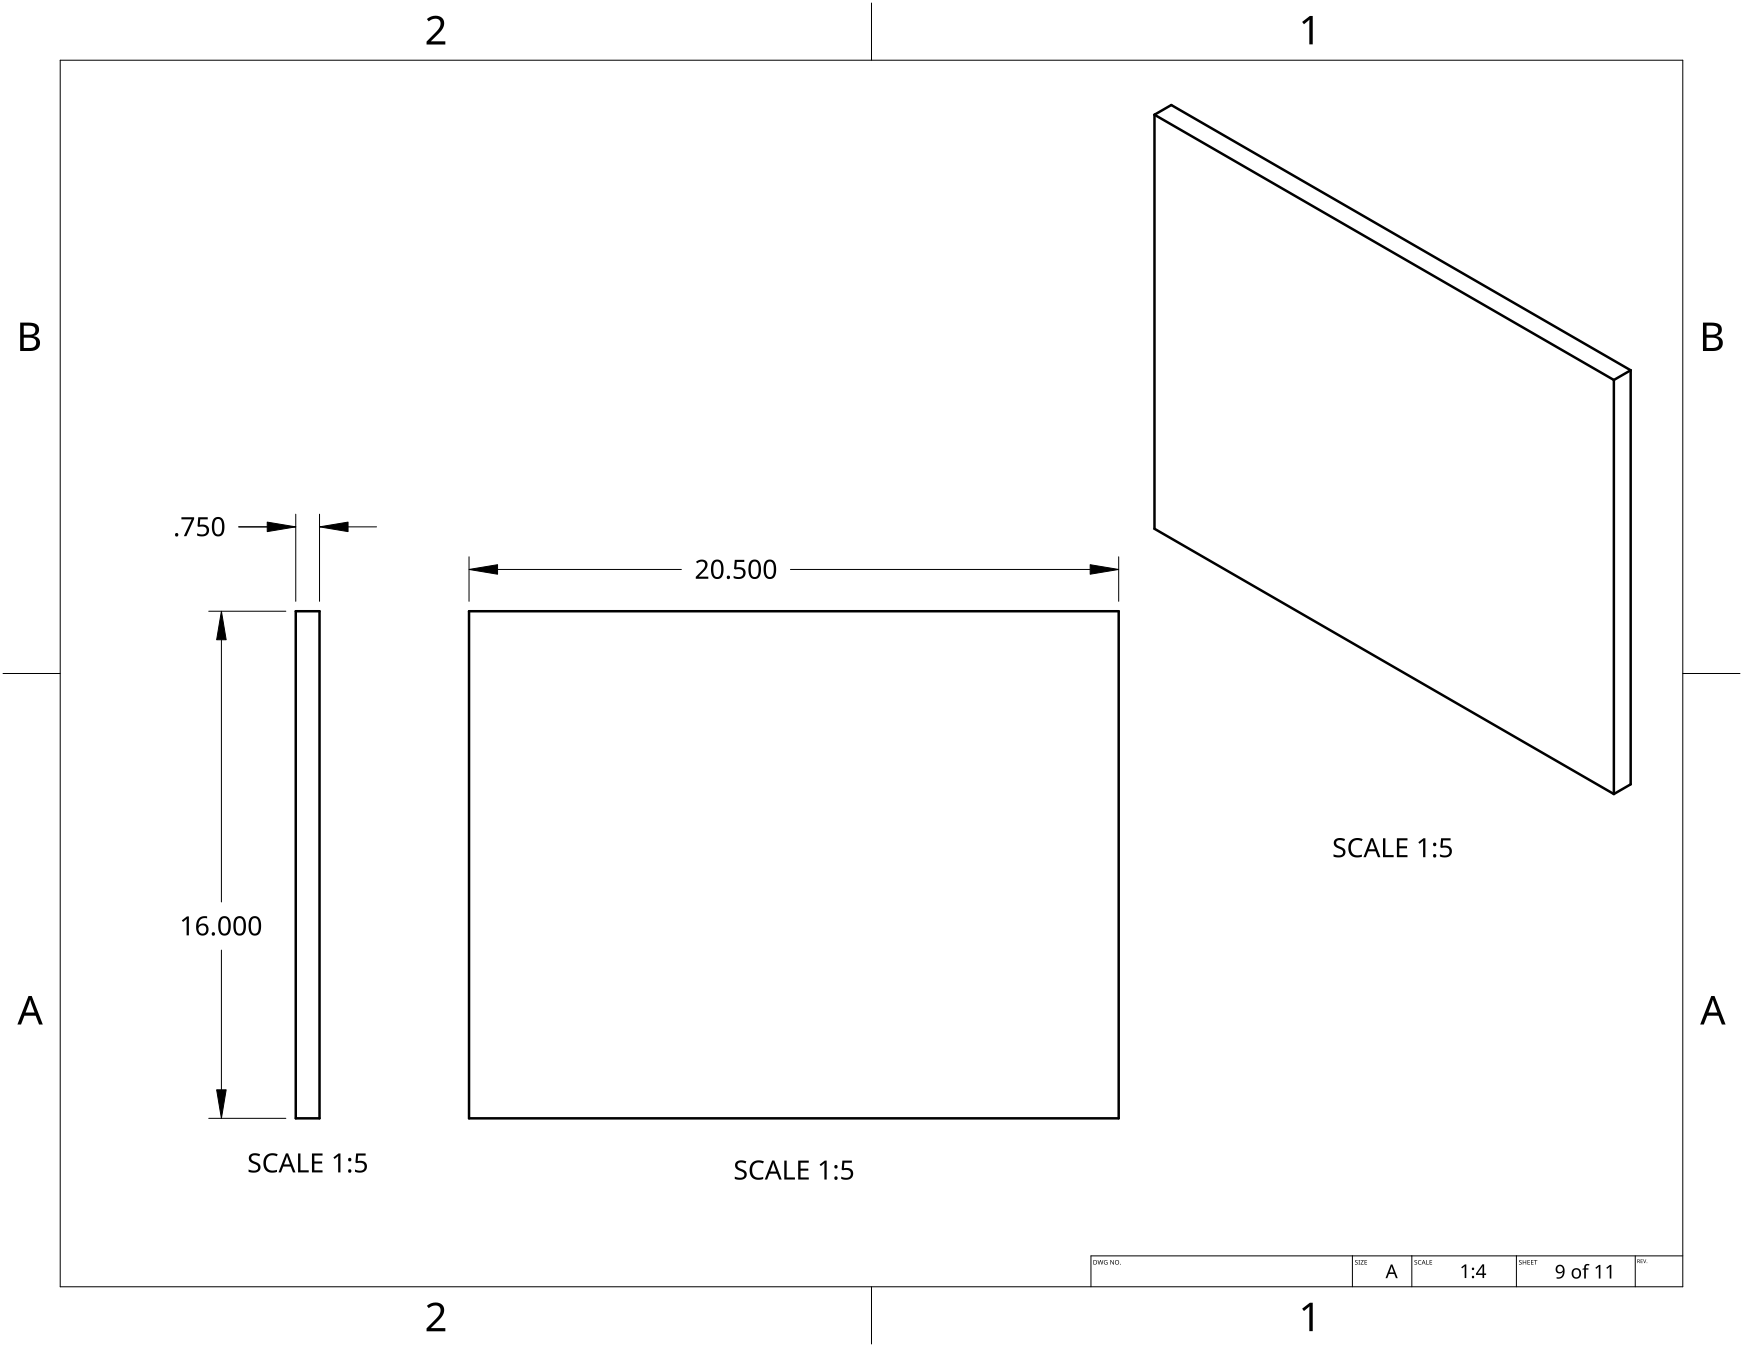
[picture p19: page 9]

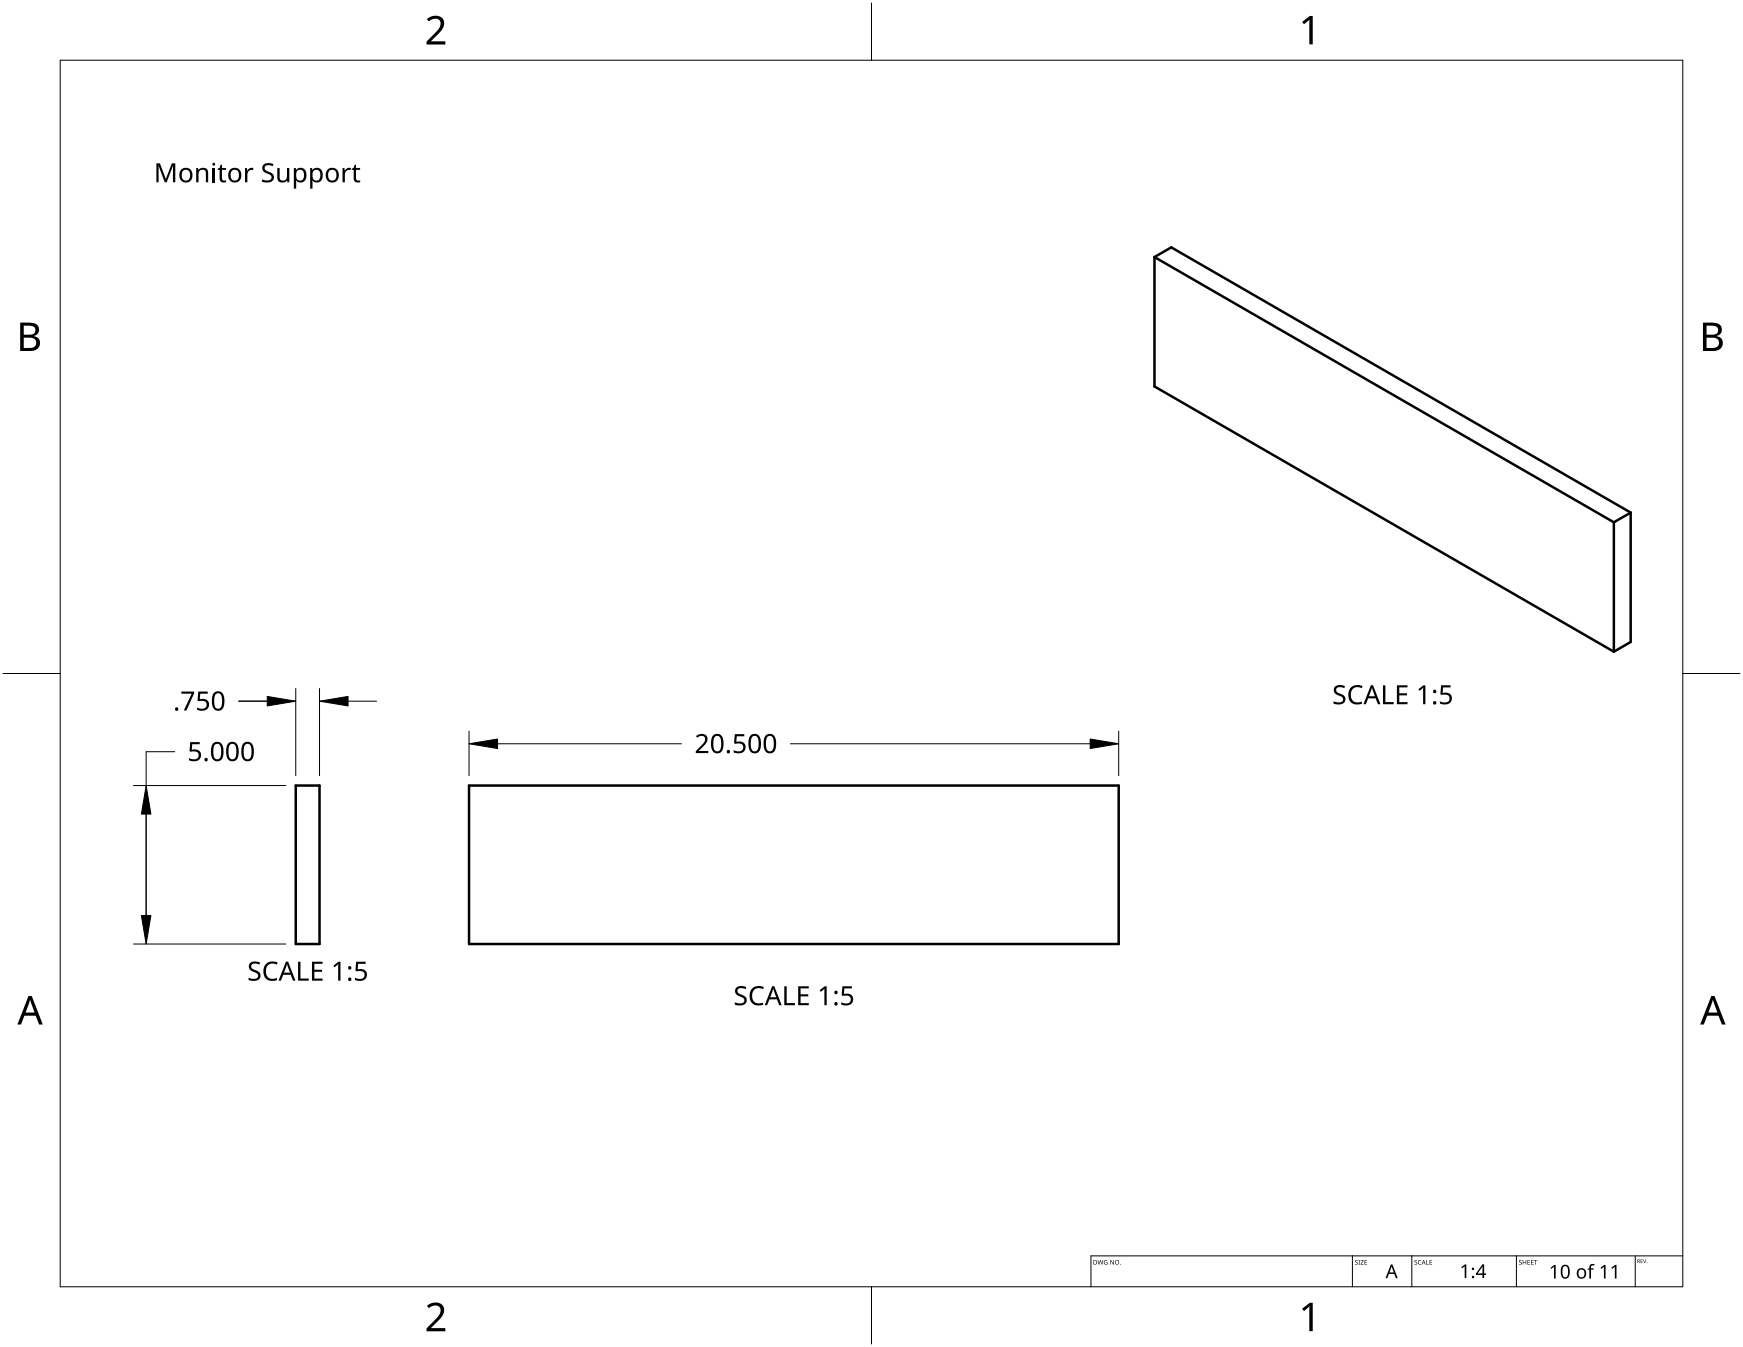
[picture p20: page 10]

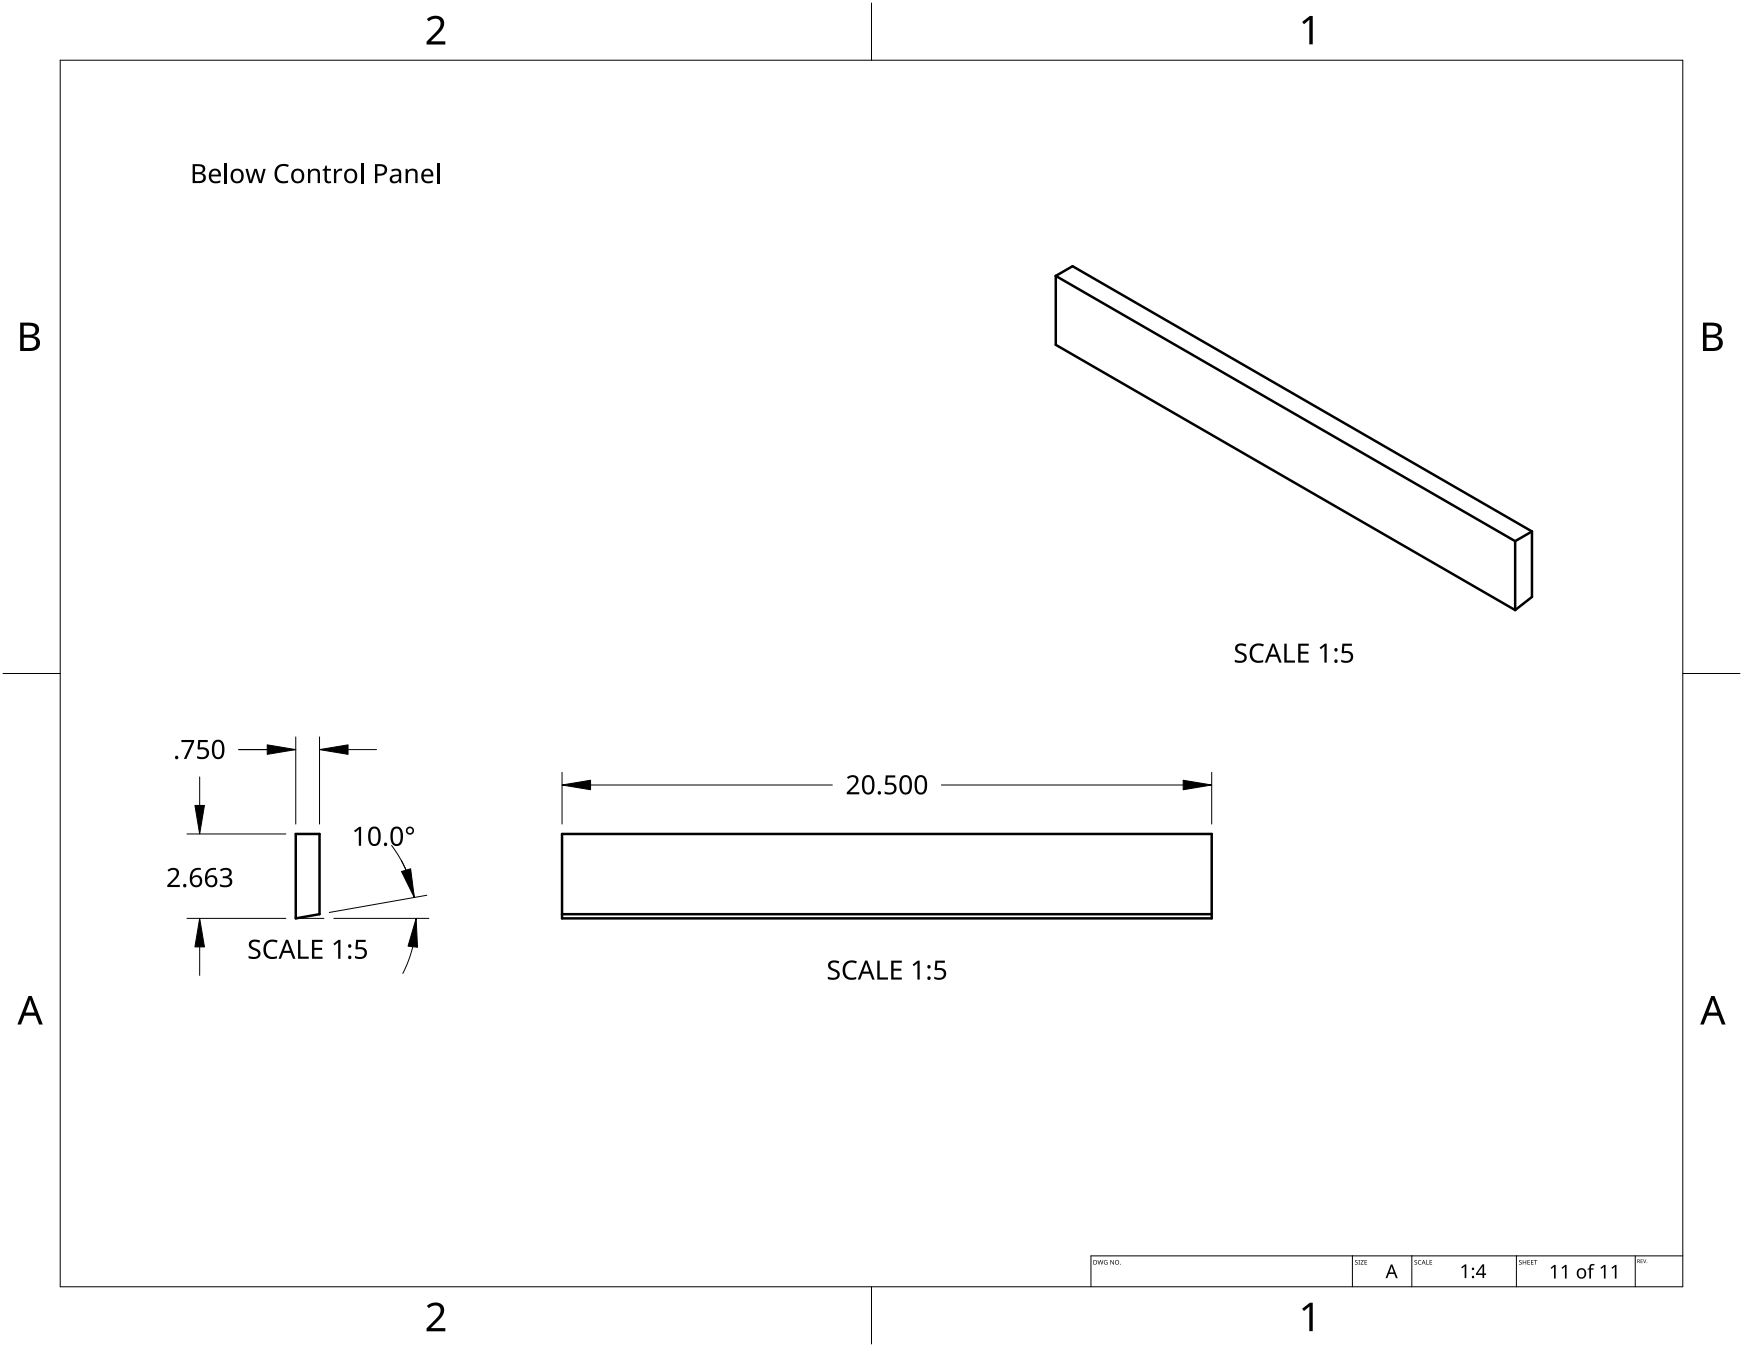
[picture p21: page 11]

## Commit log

2024-07-10 Adding/moving files
    [Arcade B.O.M..csv, OnShape Button Export.step]
2024-07-10 Update Arcade B.O.M..csv
    [Arcade B.O.M..csv]
2024-07-30 Update Control Panel Wiring.pdf
2024-09-03 Updated 3d printed parts and installation instructions
    [Button Export.step, Cabinet Export.step, Joystick Assm.step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]
2024-09-03 added user config file for recalbox.
    [recalbox-user-config.txt]
